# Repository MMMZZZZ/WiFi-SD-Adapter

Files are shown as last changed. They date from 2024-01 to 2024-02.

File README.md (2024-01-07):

# WiFi SD Adapter

## Description

microSD to SD adapter with an ESP32-C3 "inbetween". It allows wireless access to the microSD card without removing the SD card from its slot. It does this with two bidirectional bus switches that disconnect the microSD card from the host and connect it to the ESP32 for the duration of the wireless access. 

Includes a single-sided USB C connector for programming. Might only work on a USB A host port though because it's single-sided. The single-sided is necessary to not become too thick for a USB C connector. 

Gerbers, [iBOM](https://htmlpreview.github.io/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), etc. can be found in the [Exported](/Exported) folder. 

## Pics

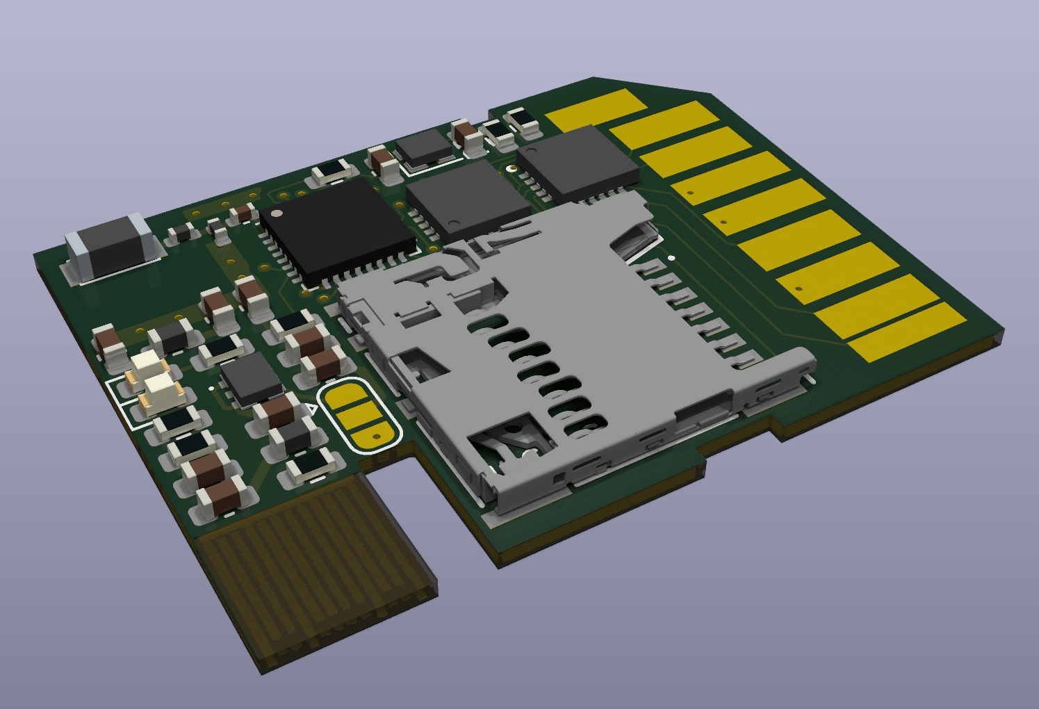
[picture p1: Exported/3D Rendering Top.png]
3D Rendering Top
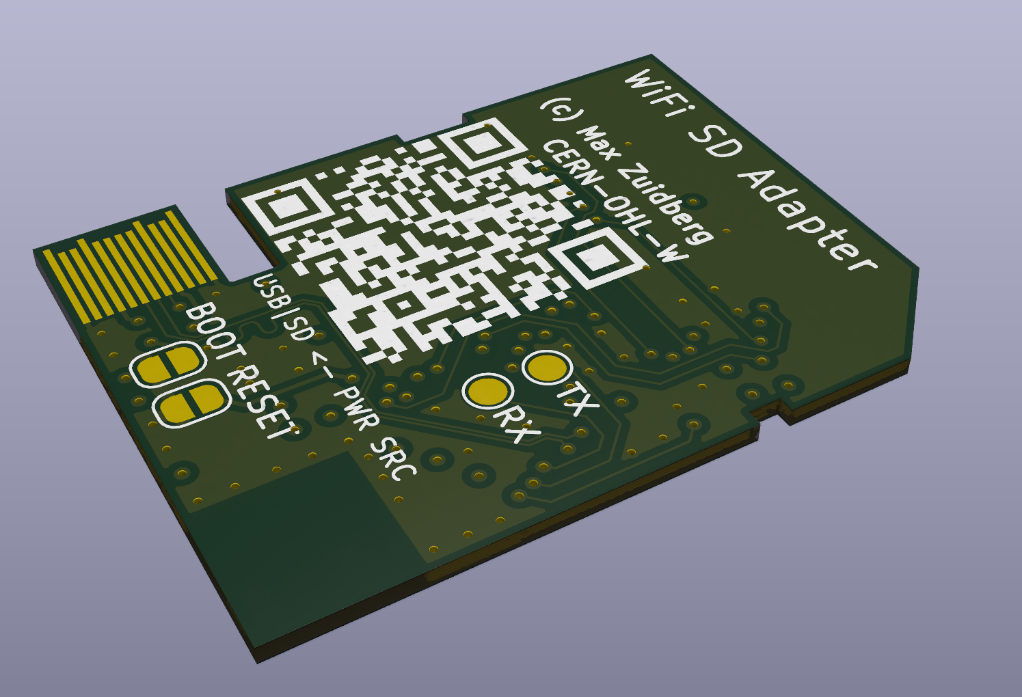
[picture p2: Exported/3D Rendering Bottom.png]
3D Rendering Bottom
|  |  |
|--|--|

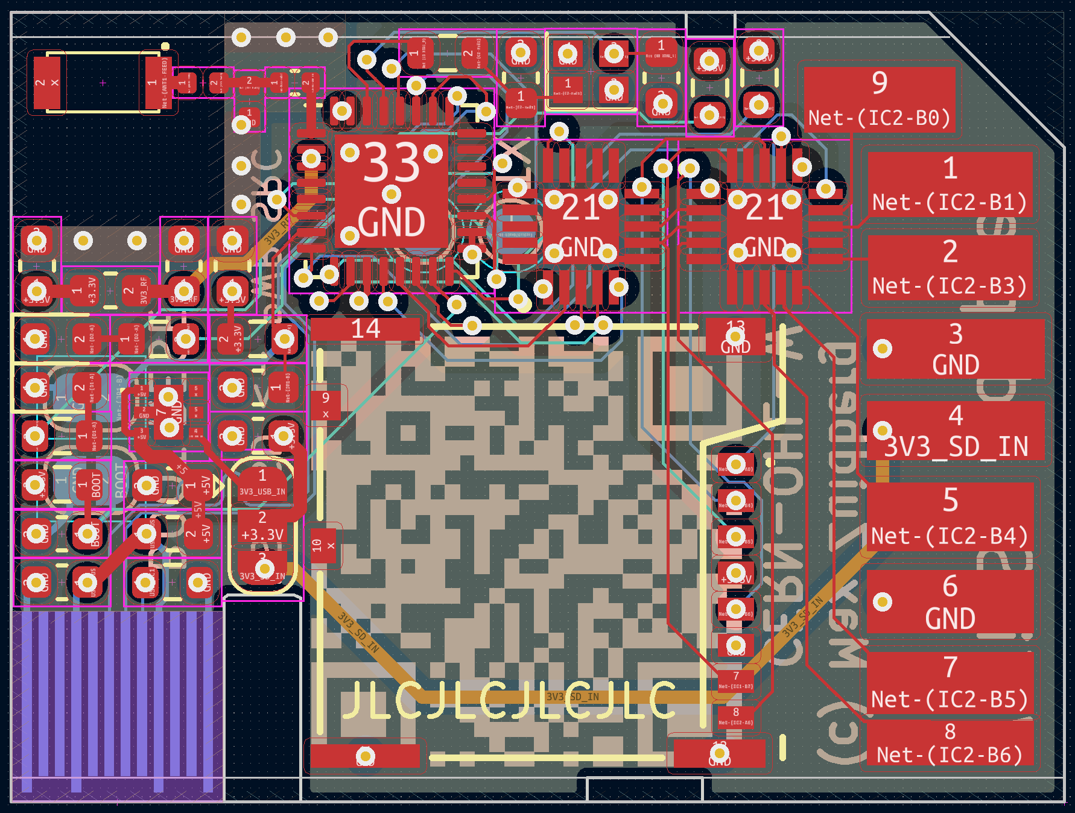
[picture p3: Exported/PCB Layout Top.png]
PCB Layout Top
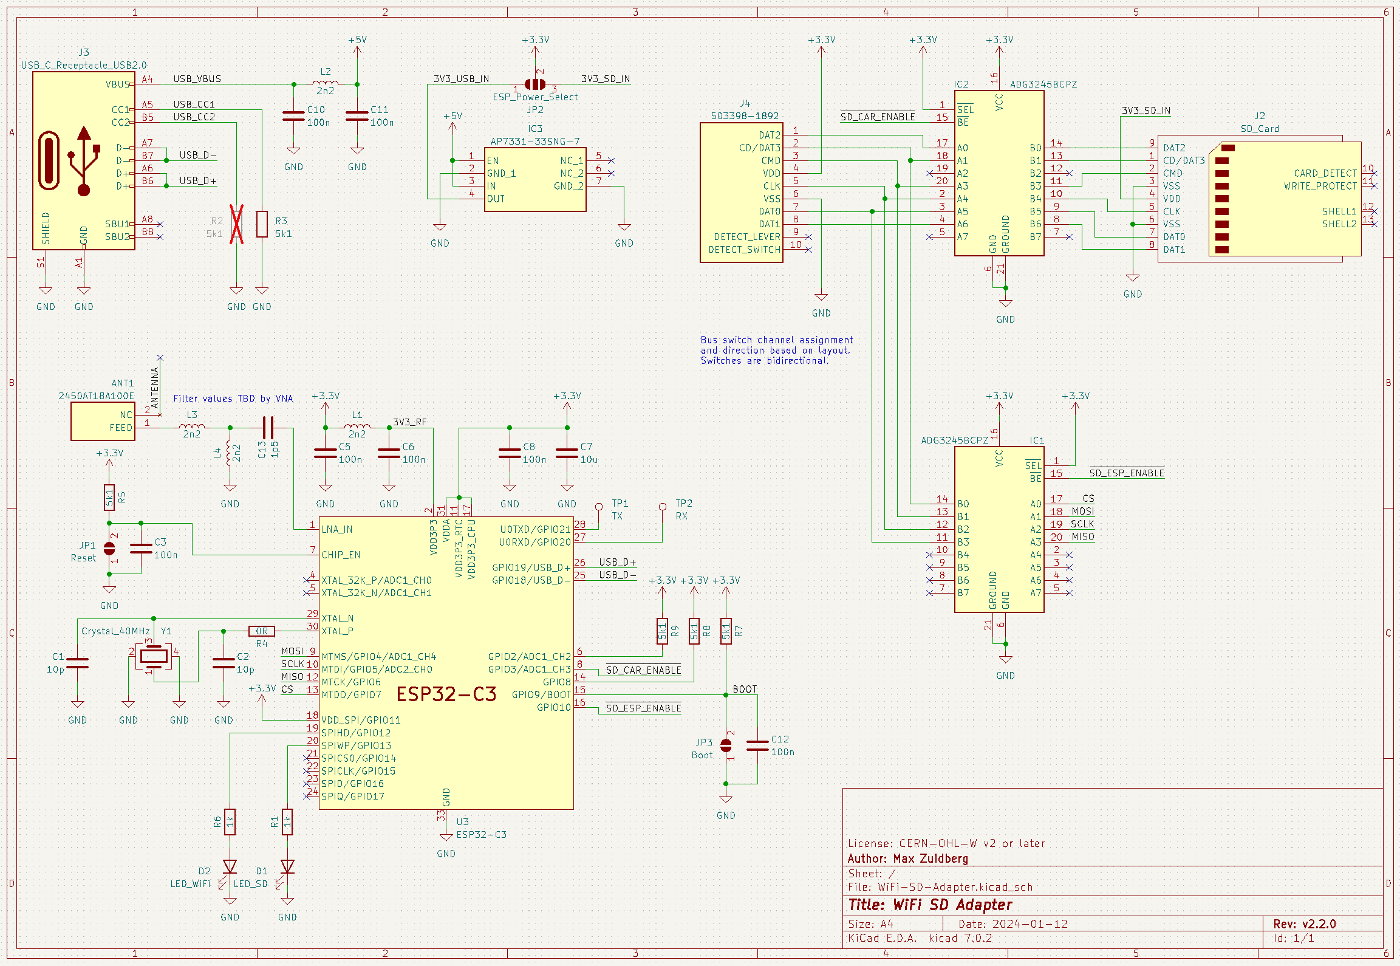
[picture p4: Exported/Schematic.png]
Schematic
|  |  |
|--|--|

## License

This project uses third-party libraries for parts and footprints (all located in the [Mouser-Parts](/Mouser-Parts) folder) to which the following licensing information may not apply. 

Copyright Max Zuidberg 2023.

This source describes Open Hardware and is licensed under the CERN-OHL-W v2 or later.

You may redistribute and modify this documentation and make products using it under the terms of the CERN-OHL-W v2 (https:/cern.ch/cern-ohl). This documentation is distributed WITHOUT ANY EXPRESS OR IMPLIED WARRANTY, INCLUDING OF MERCHANTABILITY, SATISFACTORY QUALITY AND FITNESS FOR A PARTICULAR PURPOSE. Please see the CERN-OHL-W v2 for applicable conditions. 

Source location: https://github.com/MMMZZZZ/WiFi-SD-Adapter

As per CERN-OHL-W v2 section 4.1, should You produce hardware based on these sources, You must maintain the Source Location visible on the external case of the WiFi SD Adapter or other product you make using this documentation.

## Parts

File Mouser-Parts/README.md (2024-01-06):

# Mouser Parts

## Description

These parts have been downloaded from Mousers product pages and integrated into this project using the LibraryLoader tool they recommend. Some of the parts have been modified, f.ex. to make the schematic symbol pinout more intuitive. 

## License

I couldn't easily find the licensing information on these parts and I've no idea which license applies to an auto-generated but modified schematic symbol... Some of the models (f.ex. the 3D model of the microSD slot) come from the vendor, but in that case I couldn't find a clear license on the download page or within the download either.

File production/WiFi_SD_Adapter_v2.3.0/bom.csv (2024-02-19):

Designator | Footprint | Quantity | Value | LCSC Part #
ANT1 | 2450AT18A100E | 1 | 2450AT18A100E
C1, C2 | 0603 | 2 | 10p
C10, C11, C12, C3, C5, C6, C8 | 0603 | 7 | 100n
C13 | 0402 | 1 | 1p5
C7 | 0603 | 1 | 10u
D1 | 0603 | 1 | LED_ESP
D2 | 0603 | 1 | LED_CAR
IC1, IC2 | QFN50P400X400X80-21N-D | 2 | ADG3245BCPZ
IC3 | AP733133SNG7 | 1 | AP7331-33SNG-7
J2 | SD_Card | 1 | SD_Card
J3 | USB_C_PCB_Single-Side | 1 | USB_C_Receptacle_USB2.0
J4 | 503398-1892 | 1 | 503398-1892
J5 | microSD_Card | 1 | Micro_SD_Card
JP1 | SolderJumper-2_P1.3mm_Open_RoundedPad1.0x1.5mm | 1 | Reset
JP2 | SolderJumper-3_P1.3mm_Open_RoundedPad1.0x1.5mm | 1 | ESP_Power_Select
JP3 | SolderJumper-2_P1.3mm_Open_RoundedPad1.0x1.5mm | 1 | Boot
L1, L2 | 0603 | 2 | 2n2
L3, L4 | 0402 | 2 | 2n2
R1, R6 | 0603 | 2 | 1k
R3, R5, R7, R8, R9 | 0603 | 5 | 5k1
R4 | 0603 | 1 | 12
U3 | QFN-32-1EP_5x5mm_P0.5mm_EP3.45x3.45mm | 1 | ESP32-C3
Y1 | Crystal_SMD_2016-4Pin_2.0x1.6mm | 1 | Crystal_40MHz

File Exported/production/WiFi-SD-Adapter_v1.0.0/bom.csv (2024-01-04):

Designator | Footprint | Quantity | Value | LCSC Part #
ANT1 | ANTC1608X40N | 1 | 2450AT14A0100T
C1, C2 | 0603 | 2 | 10p
C10, C11, C12, C3, C5, C6, C8, C9 | 0603 | 8 | 100n
C13 | 0402 | 1 | 1p5
C4, C7 | 0603 | 2 | 10u
D1 | 0603 | 1 | LED_SD
D2 | 0603 | 1 | LED_WiFi
J2 | SD_Card | 1 | SD_Card
J3 | USB_C_PCB_Single-Side | 1 | USB_C_Receptacle_USB2.0
J4 | 503398-1892 | 1 | 503398-1892
JP1 | SolderJumper-2_P1.3mm_Open_RoundedPad1.0x1.5mm | 1 | Reset
JP2 | SolderJumper-3_P1.3mm_Open_RoundedPad1.0x1.5mm | 1 | ESP_Power_Select
JP3 | SolderJumper-2_P1.3mm_Open_RoundedPad1.0x1.5mm | 1 | Boot
L1, L2 | 0603 | 2 | 2n2
L3 | 0402 | 1 | 2n2
R1, R6 | 0603 | 2 | 1k
R3, R5, R7 | 0603 | 3 | 5k1
R4 | 0603 | 1 | 0R
TP1 | TestPoint_Pad_D1.5mm | 1 | TX
TP2 | TestPoint_Pad_D1.5mm | 1 | RX
U1, U2 | DHVQFN-20-1EP_2.5x4.5mm_P0.5mm_EP1x3mm | 2 | 74CBTLV3245
U3 | QFN-32-1EP_5x5mm_P0.5mm_EP3.45x3.45mm | 1 | ESP32-C3
U4 | WSON-6-1EP_2x2mm_P0.65mm_EP1x1.6mm_ThermalVias | 1 | TLV73333PDRV
Y1 | Crystal_SMD_2016-4Pin_2.0x1.6mm | 1 | Crystal_GND24

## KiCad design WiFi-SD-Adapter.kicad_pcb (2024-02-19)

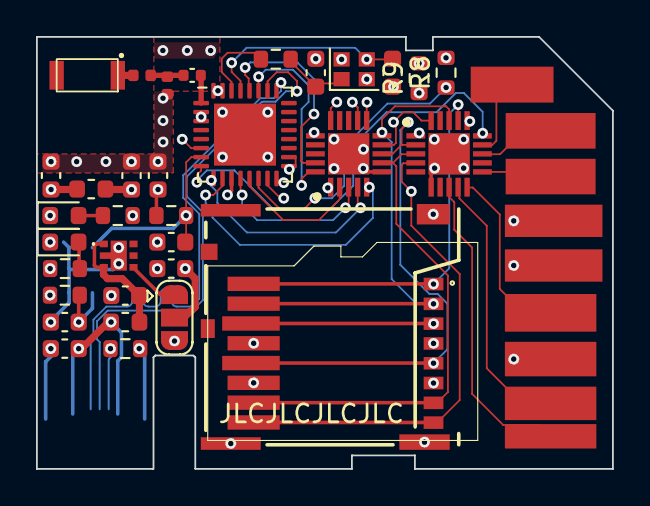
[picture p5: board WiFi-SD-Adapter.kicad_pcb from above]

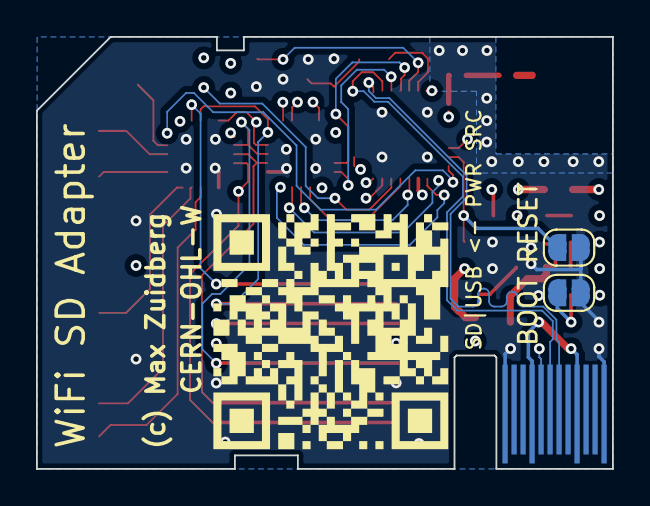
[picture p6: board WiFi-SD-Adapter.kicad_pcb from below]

Board: 6 copper layers, 32.0 x 24.0 mm, 38 parts (4 on the bottom side), 42 nets.

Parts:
ANT1: 2450AT18A100E
C1, C2: 10p; C_0603_1608Metric
C3, C5, C6, C8, C10, C11, C12: 100n; C_0603_1608Metric
C7: 10u; C_0603_1608Metric
C13: 1p5; C_0402_1005Metric
D1: LED_ESP; LED_0603_1608Metric
D2: LED_CAR; LED_0603_1608Metric
J2: SD_Card
J3: USB_C_Receptacle_USB2.0; USB_C_PCB_Single-Side
J5: Micro_SD_Card; microSD_Card
JP1: Reset; SolderJumper-2_P1.3mm_Open_RoundedPad1.0x1.5mm
JP2: ESP_Power_Select; SolderJumper-3_P1.3mm_Open_RoundedPad1.0x1.5mm
JP3: Boot; SolderJumper-2_P1.3mm_Open_RoundedPad1.0x1.5mm
L1, L2: 2n2; L_0603_1608Metric
L3, L4: 2n2; L_0402_1005Metric
R1, R6: 1k; R_0603_1608Metric
R3, R5, R7, R8, R9: 5k1; R_0603_1608Metric
R4: 12; R_0603_1608Metric
U3: ESP32-C3; QFN-32-1EP_5x5mm_P0.5mm_EP3.45x3.45mm
Y1: Crystal_40MHz; Crystal_SMD_2016-4Pin_2.0x1.6mm
locked: 503398-1892
locked#2, locked#4: ADG3245BCPZ; QFN50P400X400X80-21N-D
locked#3: AP7331-33SNG-7; AP733133SNG7

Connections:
+3.3V: C5.1, C7.1, C8.1, J5.4 (VDD), JP2.2 (C), L1.1, R1.2, R5.2, R6.2, R7.2, R8.2, R9.2, U3.11 (VDD3P3_RTC), U3.17 (VDD3P3_CPU), U3.18 (VDD_SPI/GPIO11), U3.31 (VDDA), U3.32 (VDDA), locked.4 (VDD), locked#2.1 (~SEL), locked#2.16 (VCC), locked#4.1 (~SEL), locked#4.16 (VCC)
+5V: C11.1, L2.2, locked#3.1 (EN), locked#3.3 (IN)
/3V3_RF: C6.1, L1.2, U3.2 (VDD3P3), U3.3 (VDD3P3)
/3V3_SD_IN: J2.4 (VDD), JP2.3 (B)
/3V3_USB_IN: JP2.1 (A), locked#3.4 (OUT)
/BOOT: C12.1, JP3.2 (B), R7.1, U3.15 (GPIO9/BOOT)
/CS: U3.13 (MTDO/GPIO7), locked#4.2 (A4)
/DAT1: U3.28 (U0TXD/GPIO21), locked#4.19 (A2)
/DAT2: U3.27 (U0RXD/GPIO20), locked#4.20 (A3)
/MISO: U3.10 (MTDI/GPIO5/ADC2_CH0), locked#4.5 (A7)
/MOSI: U3.12 (MTCK/GPIO6), locked#4.3 (A5)
/SCLK: U3.9 (MTMS/GPIO4/ADC1_CH4), locked#4.4 (A6)
/SD_CD/DAT3: J2.1 (CD/DAT3), locked#2.13 (B1)
/SD_CLK: J2.5 (CLK), locked#2.10 (B4)
/SD_CMD: J2.2 (CMD), locked#2.11 (B3)
/SD_DAT0: J2.7 (DAT0), locked#2.9 (B5)
/SD_DAT1: J2.8 (DAT1), locked#2.8 (B6)
/SD_DAT2: J2.9 (DAT2), locked#2.14 (B0)
/USB_CC1: J3.A5 (CC1), R3.1
/USB_D+: J3.A6 (D+), U3.26 (GPIO19/USB_D+)
/USB_D-: J3.A7 (D-), U3.25 (GPIO18/USB_D-)
/USB_VBUS: C10.1, J3.A4 (VBUS), J3.A9 (VBUS), L2.1
/microSD_CD/DAT3: J5.2 (DAT3/CD), locked.2 (CD/DAT3), locked#2.18 (A1), locked#4.10 (B4)
/microSD_CLK: J5.5 (CLK), locked.5 (CLK), locked#2.2 (A4), locked#4.8 (B6)
/microSD_CMD: J5.3 (CMD), locked.3 (CMD), locked#2.20 (A3), locked#4.9 (B5)
/microSD_DAT0: J5.7 (DAT0), locked.7 (DAT0), locked#2.3 (A5), locked#4.7 (B7)
/microSD_DAT1: J5.8 (DAT1), locked.8 (DAT1), locked#2.4 (A6), locked#4.12 (B2)
/microSD_DAT2: J5.1 (DAT2), locked.1 (DAT2), locked#2.17 (A0), locked#4.11 (B3)
/~SD_CAR_ENABLE: D2.1 (K), U3.8 (GPIO3/ADC1_CH3), locked#2.15 (~BE)
/~SD_ESP_ENABLE: D1.1 (K), U3.16 (GPIO10), locked#4.15 (~BE)
GND: C1.2, C2.2, C3.2, C5.2, C6.2, C7.2, C8.2, C10.2, C11.2, C12.2, J2.3 (VSS), J2.6 (VSS), J3.A1 (GND), J3.A12 (GND), J5.6 (VSS), JP1.1 (A), JP3.1 (A), L4.1, R3.2, U3.33 (GND), Y1.2, Y1.4, locked.6 (VSS), locked.11, locked.12, locked.13, locked#2.6 (GND), locked#2.21 (GROUND), locked#3.2 (GND_1), locked#3.7 (GND_2), locked#4.6 (GND), locked#4.21 (GROUND)
unnamed: ANT1.1 (FEED), L3.1
unnamed: C2.1, R4.2, Y1.1
unnamed: C13.1, L3.2, L4.2
unnamed: D1.2 (A), R1.1
unnamed: D2.2 (A), R6.1
unnamed: C3.1, JP1.2 (B), R5.1, U3.7 (CHIP_EN)
unnamed: R9.1, U3.6 (GPIO2/ADC1_CH2)
unnamed: R8.1, U3.14 (GPIO8)
unnamed: C13.2, U3.1 (LNA_IN)
unnamed: C1.1, U3.29 (XTAL_N), Y1.3
unnamed: R4.1, U3.30 (XTAL_P)

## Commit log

2024-01-04 Original Version
    [WiFi-SD-Adapter.kicad_pcb, WiFi-SD-Adapter.kicad_sch]
2024-01-05 LCSC Version (v2.0.0)
    Adapted schematic and layout to the parts available on LCSC at the time of ordering.
    [WiFi-SD-Adapter.kicad_pcb, WiFi-SD-Adapter.kicad_sch, bom.csv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]
2024-01-05 LCSC Version: Switched SD Contact Side... (v2.1.0)
    - Same fixes as v1.1.0 vs v1.0.0
    - Additionally, fixed some library structure issues. These were probably present in all previous versions due to the migration to GitHub and the restauration of previous versions.
    - Project QR code
    - Probably some more things that I've forgotten.
    [WiFi-SD-Adapter.kicad_pcb, WiFi-SD-Adapter.kicad_sch, bom.csv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]
2024-01-06 Followed CERN-OHL-W v2 HowTo
    [WiFi-SD-Adapter.kicad_pcb, WiFi-SD-Adapter.kicad_sch]
2024-01-12 ESP32 Pinout Fixes
    Had stuff connected to the flash SPI pins which cannot be used even if the flash is integrated into the chip.
    [WiFi-SD-Adapter.kicad_pcb, WiFi-SD-Adapter.kicad_sch]
2024-01-14 Fixed: Strapping Pins Pullups, Adjusted Layout
    [WiFi-SD-Adapter.kicad_pcb, WiFi-SD-Adapter.kicad_sch]
2024-01-17 Created Exported Files for v2.2.0
    [bom.csv, designators.csv, positions.csv]
2024-02-19 Pinout Fixes, mSD Direct Soldering Footprint
    [WiFi-SD-Adapter.kicad_pcb, WiFi-SD-Adapter.kicad_sch, bom.csv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]

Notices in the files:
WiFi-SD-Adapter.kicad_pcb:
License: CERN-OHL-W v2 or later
